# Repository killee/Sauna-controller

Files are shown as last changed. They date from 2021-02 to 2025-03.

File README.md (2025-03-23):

# Sauna-controller

<!-- Kurzbeschreibung -->
A fascinating and innovative project that implements a powerful sauna controller using ESPHome – smart, reliable, and highly impressive.

<!-- Inhaltsverzeichnis -->
- [Attention](#attention-working-with-line-voltage-is-very-dangerous-ensure-you-know-what-you-are-doing)
- [Sauna-controller](#sauna-controller)
- [Features](#features)
- [Components](#components)
- [System](#system)
- [Sauna lamp](#sauna-lamp)
- [Software](#software)
- [Circuit diagram](#circuit-diagram)
- [Things to do](#Things-to-do)
- [Installation](#installation)
- [Usage](#usage)
- [Repository Structure](#repository-structure)
- [Contributing](#contributing)
- [Inspiration](#inspiration)

# Attention: Working with line voltage is very dangerous! Ensure you know what you are doing!

# Sauna-controller
Sauna Controller with ESP8266/ESP32 and [ESPHome](https://esphome.io/) for integration with [Home Assistant](https://www.home-assistant.io/).

For about 60€, you get an awesome sauna controller!

The sauna controller is built from scratch with no additional components needed. Integration is done with Home Assistant, and the controller itself is built around the excellent [ESPHome](https://esphome.io/).

# Features
- Real PID controller
- Power and energy calculation
- Customizable
- No cloud dependency
- Remote access
- Expandable
- Affordable
- Reliable
- Easy to build
- Easy to use
- Open source

If you find a sauna controller with more features, let me know ;-)!

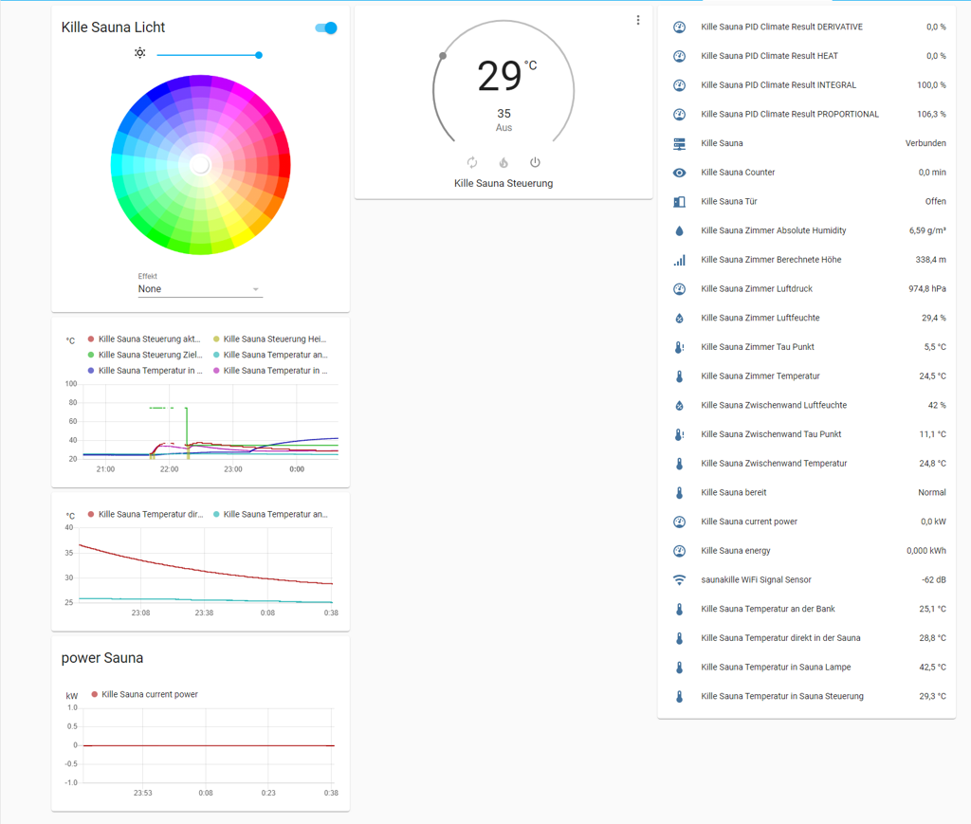
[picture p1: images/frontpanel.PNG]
Home Assistant

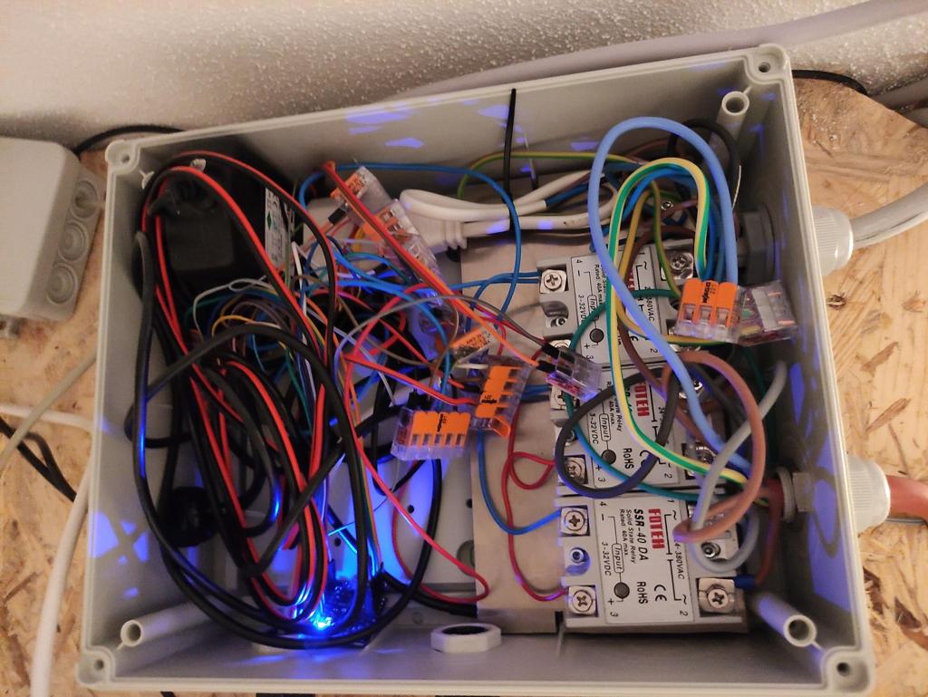
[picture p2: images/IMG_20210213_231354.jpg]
Sauna Controller

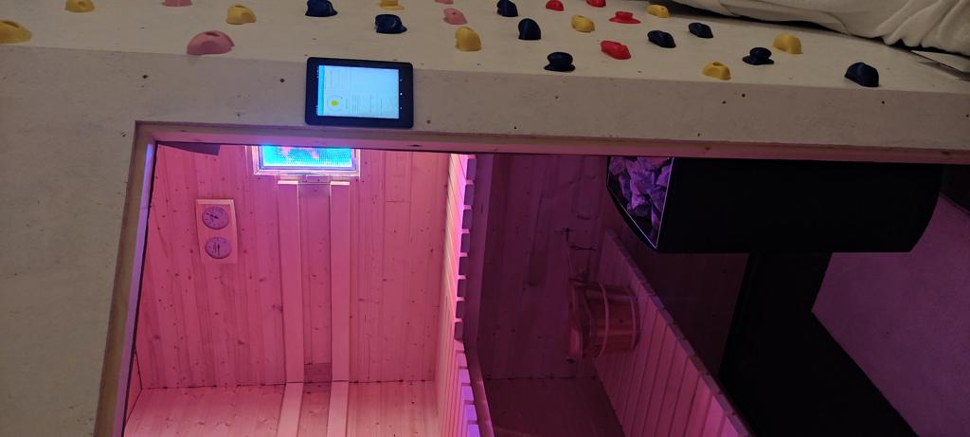
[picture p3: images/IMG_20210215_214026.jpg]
Sauna


# Components
Only a few components are needed:

1. **The brain of the Sauna Controller**: A Wemos D1 ESP8266 or any other device running ESPHome.

2. **Temperature sensors**: At least one DS18B20 to measure the temperature in the sauna. My setup includes 4 DS18B20 sensors to measure temperature at different locations (top of the sauna, lower bench, sauna controller, and sauna lamp).

3. **Thermal fuse**: A crucial component. If something goes wrong and the heater overheats, the thermal fuse burns out and switches off the heater, cutting the voltage for the high current switches.

4. **High current/voltage switch to heat the sauna**: I chose SSR relays like 3 SSR-40DA. SSR relays are wear-free and allow for easy PID controller implementation without noise.

5. **Optional door sensor**: I have a reed contact in the sauna door. If the door is open, the controller can switch off the sauna. The controller resets a timer when the door is opened, which is useful for extended sauna sessions.

6. **Optional additional sensors**: I use various other sensors to measure temperature in the room, between the sauna wall and the room wall, and humidity.

7. **Sauna lamp**: The controller also drives WS2812b LEDs for the sauna lamp, allowing for fun lighting effects.

8. **Junction box, cables, and other small components**.

# System
!Attention! Working with line voltage is very dangerous! Ensure you know what you are doing!

The heart of a sauna is, of course, the heater. Most commonly used heaters in Europe use 3-phase power and have a power rating of over 3kW, with a current of less than 16A. A normal switch for 3 phases is sufficient. The SSR-40DA, even the cheap copies, work well. Most SSR-40DA relays do not switch at 3.3V, even if the control LEDs turn on. With a simple NPN transistor, the three SSR-40DA relays get 5V control voltage and switch correctly. I mounted the SSR-40DA on an aluminum plate and tested the temperature of the plate. In the junction box, the temperature is about 50°C with my 7.5kW heater during the heating phase, which is acceptable.

I decided to switch the heater's 3 phases together for the lowest cable dissipation. The "PWM" has a long period of about 60 seconds, and the SSR-40DA relays have no switching wear. For safety, it is crucial to have a thermal fuse in the sauna. If the controller hangs or another bug occurs, the sauna can overheat, potentially leading to a fire. I use a thermal fuse with a 120°C rating in the control voltage for the SSR-40DA.

The rest of the controller is very simple. One DS18B20 measures the temperature, and that's it. The rest is handled by the ESP8266 (an ESP32 is also possible). See the Software section for more details. This setup provides a sauna controller that is more flexible than most commercial controllers, but for less money!

With the door sensor, you get additional features. A reed contact and magnet make it simple to wire like a normal switch with an internal pull-up. For about 1€, you can measure different temperatures in the sauna or the room.

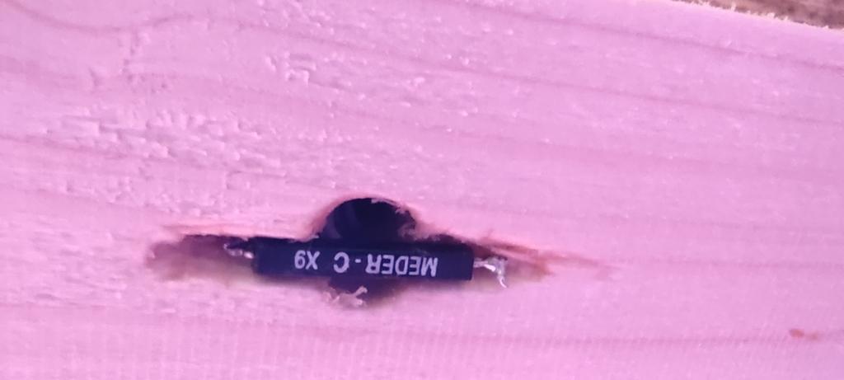
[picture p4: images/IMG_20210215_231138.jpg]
door sensor


I measure the temperature and humidity between the sauna wall and the room wall. The software calculates the dew point. If the dew point falls below the temperature, it can result in mildew. This allows me to react before mildew forms.

# Sauna lamp
A normal sauna lamp with a light bulb is not suitable for me. The biggest problem is the heat. Saunas with 100°C and LEDs don't work well together. I built a lamp with WS2812 LEDs, designed like an infinity lamp. The lamp dissipates heat with a large aluminum plate mounted on the outside wood. An acrylic "window" faces the sauna. With a temperature sensor in the lamp, it is possible to switch off the lamp before the LEDs overheat.

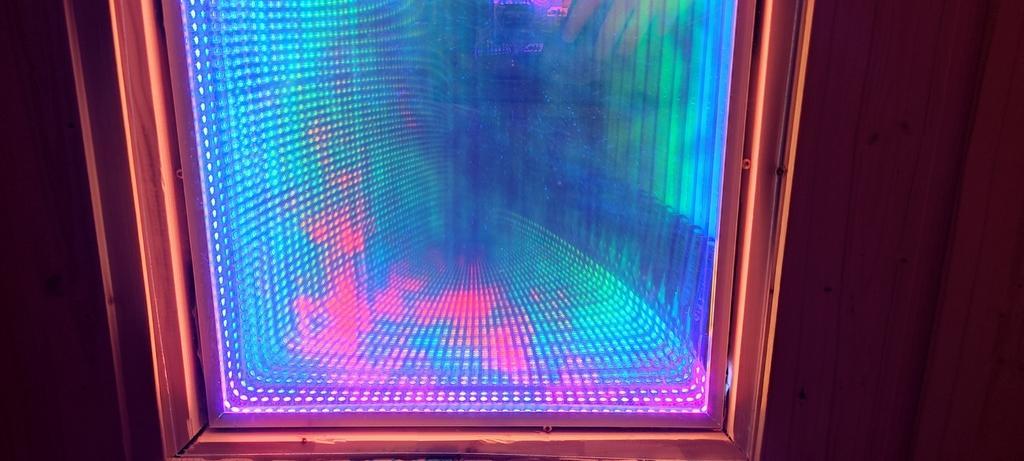
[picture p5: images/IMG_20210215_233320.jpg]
Sauna lamp


# Software
The sauna controller's entire UI is in [Home Assistant](https://www.home-assistant.io/). This is very convenient, as it prevents kids from accidentally turning on the sauna while playing in the sauna room. The software running on the controller is built with the excellent [ESPHome](https://esphome.io/). The configuration is in the sauna_controller.yaml file and is easily customizable for different setups.

In the Home Assistant frontend, you can set the temperature, switch the sauna on, and receive notifications when the sauna is ready. The controller itself manages the temperature without Home Assistant. If Home Assistant crashes, the sauna will not overheat. The controller regulates the heater with a PID controller, which works great. Compared to a simple two-point controller, the temperature is very stable. With a two-point controller, the temperature variation in the sauna is about 8°C. My heater makes noise when it switches off and on with a two-point controller, but with the PID controller, it is practically noiseless.

The PID constants are calculated with autotune. The constants are suitable for my sauna but can be optimized for different setups.

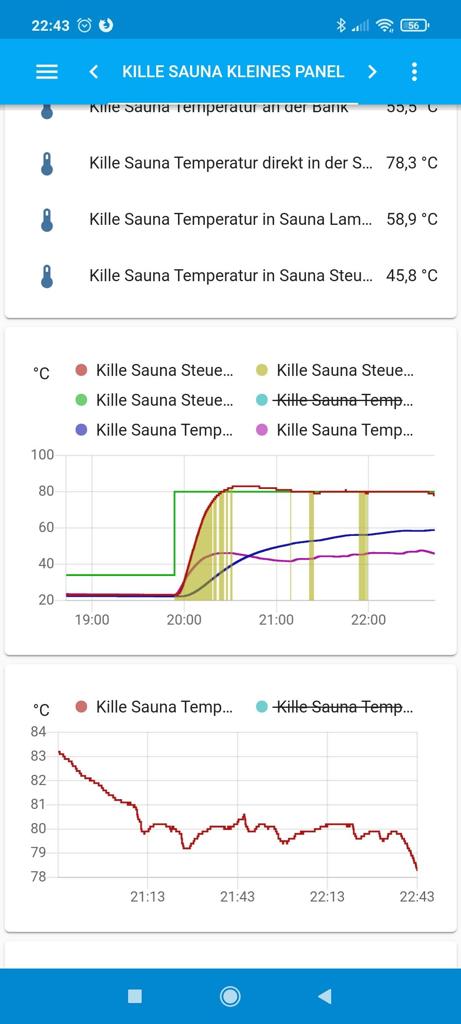
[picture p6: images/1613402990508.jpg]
temperature regulation


The controller also calculates the actual power needed for the sauna and integrates the power for the total energy consumption. This allows you to calculate the costs for your sauna sessions ;-).

With the door sensor, the timer resets if the door is opened. This is very convenient, as you don't need to remember to reset the timer. If you forget to close the door, the sauna will switch off.

I can measure different temperatures. Building a LED lamp for the sauna without overheating the LEDs was challenging. With a temperature sensor in the lamp, I was able to test if the heat dissipation was sufficient. The second attempt was successful ;-).

I've tried my best to comment the easy YAML config file, so it's easy to understand. It can be a good starting point for your own implementation.

# Circuit diagram
This is very simple. Normally, it is not needed, and the ESPHome YAML file is sufficient. But for reference, here is the circuit diagram:

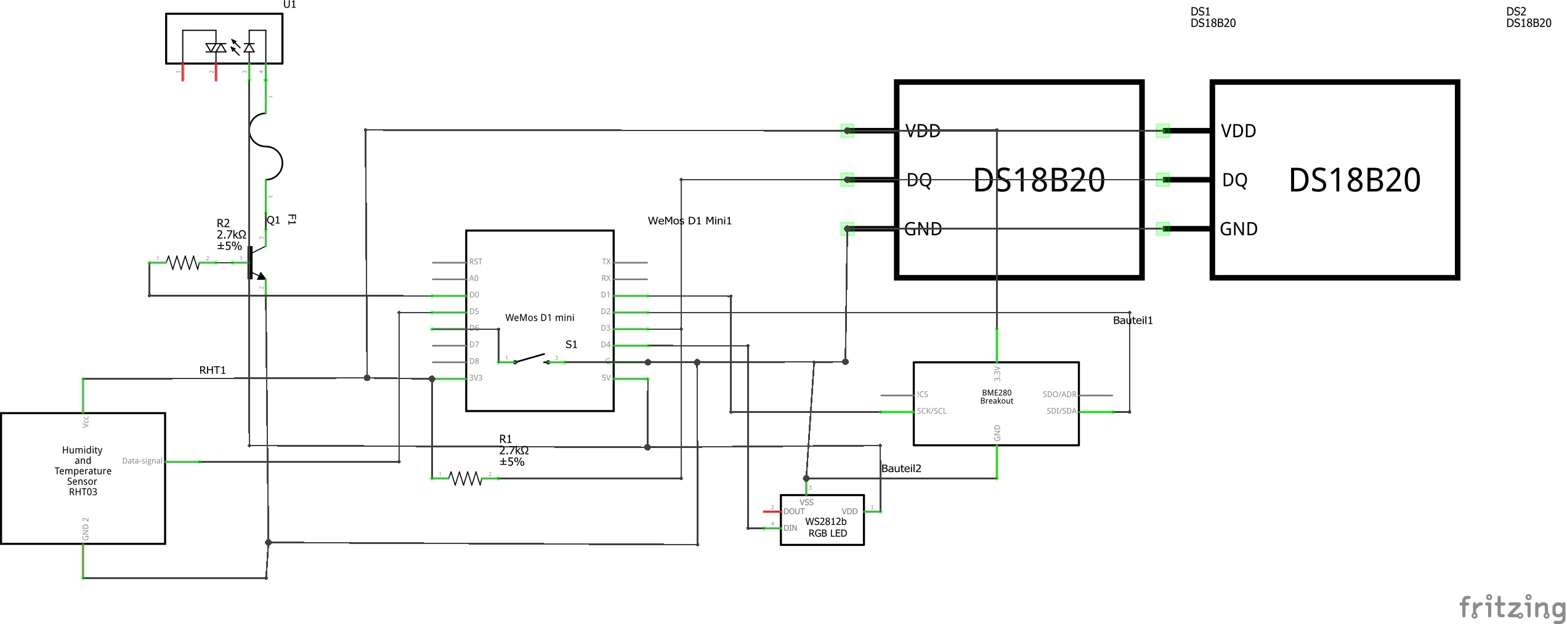
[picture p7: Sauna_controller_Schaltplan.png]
circuit diagram


## Circuit Diagram Explanation
1. **ESP8266/ESP32**: The brain of the controller, running ESPHome.
2. **SSR Relays (SSR-40DA)**: Used to switch the high current needed for the sauna heater. Controlled by the ESP8266/ESP32 through a transistor to provide the necessary control voltage.
3. **Temperature Sensors (DS18B20)**: Placed at various points to monitor the temperature inside the sauna (one for the pid at the seeling), optinal on the heatsink, and optinal in the room.
4. **Thermal Fuse**: !IMPORTANT! Provides a safety mechanism to cut off power if the temperature exceeds a safe limit.
5. **Door Sensor**: Optinal a reed switch that detects if the sauna door is open or closed.
6. **Sauna Lamp (WS2812 LEDs)**: Provides lighting inside the sauna with fun effects, controlled by the ESP8266/ESP32.
7. **Power Supply**: Provides the necessary power to the ESP8266/ESP32 and other components.

# Things to do
With the door contact, it would be possible to measure the time for a sauna session. A simulated sand clock with LEDs like WS2812 would be nice. Find more things to automate, such as switching off the room climate if the sauna is running, etc.

Very nice projects!

## Installation
- Flash the firmware with [ESPHome](https://esphome.io/).
- Connect your ESP8266/ESP32 device according to the pin mapping.
- Follow the on-screen instructions from Home Assistant and adjust settings in the YAML files as needed.

## Usage
- Integrate the controller with Home Assistant for easy control.
- Use the web interface to set target temperatures, view sensor status, and monitor energy consumption.
- The minimal version (sauna_simpler.yaml) is great for a lean setup, while sauna_controller.yaml offers extra features if you want advanced functionality.

## Repository Structure
- README.md – Project overview and documentation.
- sauna_simpler.yaml – Minimal configuration for essential operation.
- sauna_controller.yaml – A more feature-rich configuration with extra sensors and extras.
- images/ – Contains photos and the circuit diagram.

## Contributing
We welcome improvements!  
If you have suggestions or bug fixes, please open an issue or a pull request.

# Inspiration
This project was heavily inspired by:

https://github.com/bastiaanterhorst/sauna-automation  
https://github.com/quicklywilliam/saunakit

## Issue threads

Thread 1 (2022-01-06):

Fine regulation with ac_dimmer

eldarmusin, 2022-01-06:
I would like to contribute for those who cares in 4 steps.

**T Sensor**
For an experimental purpose, a used a DHT22 than switched for a 18ds20. Kept in code for the better comprehension.

**T Regulator**
I have used the same [pid ](https://esphome.io/components/climate/pid.html) component for the regulation, but as output used the [ac_dimmer](https://esphome.io/components/output/ac_dimmer.html) component. To set up the PID values Kp, Kd, Ki please see below.

**Dimmable Output**
I used the ac_dimmer component because of the [triac hardware](https://robotdyn.com/ac-light-dimmer-module-1-channel-3-3v-5v-logic-ac-50-60hz-220v-110v-1.html). The main advantages are:
- Price 2.5 € vs 10 € for an SSR
- The on state voltage is about 0.85V versus 1.6V of an SSR. And the power dissipation is than twice lower, as well as the dissipator for it
- You manage the max voltage on it. So you can reduce the wear of the oven (see max_power parameter)
- You manage the min voltage on it. So you can avoid the high frequency oscillations due to approaching the set point

**Set up PID**
I referred to the file [[Russian](http://www.termodat.ru/pdf/pid.pdf)] .

1. Set Kp = 100, Kd = Ki = 0 and let the system heat
2. You will see a Temperature curve of your sensor like this
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
3. After 4-5 oscillations, calculate the values as follows and report them to the code:
- Kp = 1.2 * DeltaT
- Ki = 1.5 * Tau
- Kd = 0.2 * Tau

Here is my code
sensor:
  - platform: dht
    pin: GPIO14
    temperature:
      id: sauna_temperature_sensor
      name: "Sauna temperature"
    humidity:
      name: "Sauna humidity"
    update_interval: 1s
    model: DHT22

output:
  - platform: ac_dimmer
    id: dimmer1
    max_power: 0.8
    min_power: 0.2
    gate_pin: GPIO32
    zero_cross_pin:
      number: GPIO33
      mode:
        input: true
      inverted: yes

climate:
  - platform: pid
    id: pid_climate
    name: "PID Sauna Controller"
    visual:
      min_temperature: 40 °C
      max_temperature: 90 °C
      temperature_step: 1 °C
    sensor: sauna_temperature_sensor
    default_target_temperature: 70°C
    heat_output: dimmer1
    control_parameters:
      kp: 1.44
      ki: 13.5
      kd: 1.8

killee, 2022-01-23:
Hi @eldarmusin

Thanks for your suggestions!

I didn't think about a triac control.
The power losses will be better and the power control is better.

Private people has also no responsibility about a not in Phase current.

I don't like this kind of triac power control, but that's my issue 😉.
Can you hear some line noise?

Why didn't you use the auto PID tune from esphome?

Regards

eldarmusin, 2022-02-23:
Yes I'm hearing a regulation noise. But after some time, just ignoring it.

The Auto PID hasn't worked for me for some reason. Had to find another solution.

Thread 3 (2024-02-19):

Which NPN Transistor?

janCGN, 2024-02-19:
Hey @killee ,
I have rebuilt the setup so far. Many thanks for the great description.
However, I am currently facing the problem that when "heating=off" the voltage at the SSR is 5V and when I switch it on it drops to 1.9V - so the 5V is only present in the "off" state. Is that normal?
You wrote something about the NPN transistor, can you tell me which one you used?

Thanks in advance

killee, 2024-03-15:
I'm so sorry for the late response.

I've used a bc547 with a 1kOhm resistor for the base.

I don't understand exactly where you measure the voltage. Can you describe it a bit?

Regards

Closed 2025-03-21.

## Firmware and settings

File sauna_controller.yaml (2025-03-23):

# Explanation:
# This YAML file is the minimalist approach - just the essentials to keep your sauna controller running.
# No unnecessary extras, simple and uncomplicated. Just the way you need it sometimes.

substitutions:
  devicename: saunakille
  user: Kille
  fullname: Killes Sauna
  max_power_generic: "1.0"
  #power of the sauna oven (kw dividet 100)
  power_of_sauna_oven: "0.075"

esphome:
    name: $devicename
    on_boot:
      priority: 200
      then:
        - climate.control:
            id: sauna_climate
            mode: 'OFF'

esp8266:  
  #platform: ESP8266
  board: d1_mini

wifi:
  ssid: !secret wifi_ssid
  password: !secret wifi_password

  # Enable fallback hotspot (captive portal) in case wifi connection fails
  ap:
    ssid: ${devicename} Fallback Hotspot"
    password: !secret wifi_password

#captive_portal:

# Enable logging
logger:

# Enable Home Assistant API
api:
  encryption:
    key: change_me

ota:
  platform: esphome
  password: !secret esp_password
  
#web_server:
#  port: 80

#Pinmapping
#D0 Sauna oven -> move to D7!
#D1 SCL
#D2 SDA
#D3 dallas
#D4 WS2812
#D5 DHT22
#D6 door reed contact

globals:
  - id: count_global_int
    type: int
    restore_value: no
    initial_value: '0'
  - id: count_global_door_int
    type: int
    restore_value: no
    initial_value: '0'

#the SSR relays for the sauna oven. They are switchted with a BC847 
output:
  - platform: slow_pwm
    pin: D0
    id: sauna_ofen_pwm
    period: 60s    

switch:
  - platform: template
    name:  ${user} Sauna PID Climate Autotune
    turn_on_action:
      - climate.pid.autotune: sauna_climate    


one_wire:
  - platform: gpio
    pin: D3
    #update_interval: 10s

i2c:
  sda: D2
  scl: D1
  scan: True
  id: bus_a


# Individual sensors
sensor:
  - platform: dallas_temp
    address: 0xD60516A1D5F6FF28 #Sensor on the seeling near by oven
    name: ${user} Sauna Temperatur direkt in der Sauna
    id: sauna_temp
    update_interval: 10s
  - platform: dallas_temp
    address: 0x11012042F8B5E128 #Sensor in the Sauna lamp 
    name: ${user} Sauna Temperatur in Sauna Lampe
  - platform: dallas_temp
    address: 0x8D0316A1D0C4FF28 #in the electronic at the SSR Relais
    name: ${user} Sauna Temperatur in Sauna Steuerung
  - platform: dallas_temp
    address: 0x07012042F262F228 #at a bench
    name: ${user} Sauna Temperatur an der Bank

  - platform: bme280_i2c #a sensor in the room of the Sauna
    temperature:
      name: ${user} Sauna Zimmer Temperatur
      oversampling: 16x
      id: bme280_temperature
    pressure:
      name: ${user} Sauna Zimmer Luftdruck
      id: bme280_pressure
    humidity:
      name: ${user} Sauna Zimmer Luftfeuchte
      id: bme280_humidity
    address: 0x76
    update_interval: 60s
  - platform: template
    name: ${user} Sauna Zimmer Berechnete Höhe
    lambda: |-
      const float STANDARD_SEA_LEVEL_PRESSURE = 1013.25; //in hPa, see note
      return ((id(bme280_temperature).state + 273.15) / 0.0065) *
        (powf((STANDARD_SEA_LEVEL_PRESSURE / id(bme280_pressure).state), 0.190234) - 1); // in meter
    update_interval: 60s
    icon: 'mdi:signal'
    unit_of_measurement: 'm'
  - platform: template
    name: ${user} Sauna Zimmer Absolute Humidity
    lambda: |-
      const float mw = 18.01534;    // molar mass of water g/mol
      const float r = 8.31447215;   // Universal gas constant J/mol/K
      return (6.112 * powf(2.718281828, (17.67 * id(bme280_temperature).state) /
        (id(bme280_temperature).state + 243.5)) * id(bme280_humidity).state * mw) /
        ((273.15 + id(bme280_temperature).state) * r); // in grams/m^3
    accuracy_decimals: 2
    update_interval: 60s
    icon: 'mdi:water'
    unit_of_measurement: 'g/m³'
  - platform: template
    name: ${user} Sauna Zimmer Tau Punkt
    lambda: return (243.5*(log(id(bme280_humidity).state/100)+((17.67*id(bme280_temperature).state)/(243.5+id(bme280_temperature).state)))/(17.67-log(id(bme280_humidity).state/100)-((17.67*id(bme280_temperature).state)/(243.5+id(bme280_temperature).state))));
    unit_of_measurement: °C
    icon: 'mdi:thermometer-alert'
  - platform: dht #a sensor in the gap beetween the sauna wall and the wall of the room
    model: dht22    
    pin: D5
    temperature:
      name: ${user} Sauna Zwischenwand Temperatur
      id: dht22_temperature
    humidity:
      name: ${user} Sauna Zwischenwand Luftfeuchte
      id: dht22_humidity
  - platform: template
    name: ${user} Sauna Zwischenwand Tau Punkt
    lambda: return (243.5*(log(id(dht22_humidity).state/100)+((17.67*id(dht22_temperature).state)/(243.5+id(dht22_temperature).state)))/(17.67-log(id(dht22_humidity).state/100)-((17.67*id(dht22_temperature).state)/(243.5+id(dht22_temperature).state))));
    unit_of_measurement: °C
    icon: 'mdi:thermometer-alert'
    update_interval: 60s
  - platform: template #gives the counter without a change back to HA (for debugging or so)
    name: ${user} Sauna Counter
    unit_of_measurement: 'min'
    lambda: |-
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

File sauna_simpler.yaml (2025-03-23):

# Explanation:
# This YAML file is the minimalist approach - just the essentials to keep your sauna controller running.

substitutions:
  devicename: "Sauna Controller"
  internalname: "sauna-controller"
  #power of the sauna oven kw
  power_of_sauna_oven: "6.50"

esphome:
  name: "${internalname}"
  on_boot:
    priority: 200
    then:
      - climate.control:
          id: sauna_climate
          mode: 'OFF'

esp32:
  board: esp32dev
  framework:
    type: arduino

wifi:
  ssid: !secret wifi_ssid
  password: !secret wifi_password

  # Enable fallback hotspot (captive portal) in case wifi connection fails
  ap:
    ssid: ${devicename}
    password: !secret wifi_password


# Enable logging
logger:

# Enable Home Assistant API
api:
  #password: !secret esp_password

ota:
  platform: esphome
  password: !secret esp_password


one_wire:
  - platform: gpio
    pin: 23

globals:
  - id: sauna_runtime
    type: int
    restore_value: no
    initial_value: '0'  # In seconds

sensor:
  # Change the addresses below according to the addresses present in your controller
  - platform: dallas
    address: 0x523c01d607567d28
    name: "${devicename} Heatsink"
    id: heatsink_temp
    entity_category: diagnostic

  - platform: dallas
    address: 0x4d0120633b2fc328
    name: "${devicename} Above Oven"
    id: sauna_temp

  - platform: dallas
    address: 0x623c01d607fa4728
    name: "${devicename} Room"

  - platform: template
    name: "Timer ${devicename}"
    id: sauna_timer
    unit_of_measurement: s
    accuracy_decimals: 0
    lambda: |-
      return id(sauna_runtime);

  - platform: pid
    climate_id: sauna_climate
    name: "Sauna Current Power ${devicename}"
    type: HEAT
    filters:
      - multiply: ${power_of_sauna_oven}
      - multiply: 0.01
    unit_of_measurement: 'kW'
    id: power_of_sauna
    force_update: true

  - platform: integration
    name: "Sauna Energy ${devicename}"
    sensor: power_of_sauna
    time_unit: h
    restore: true
    state_class: total_increasing
    device_class: energy

binary_sensor:
  - platform: template
    name: "${devicename} Sensor Error"
    id: sauna_sensor_failure
    lambda: |-
      if (isnan(id(sauna_temp).state) || !id(sauna_temp).has_state()) {
        return true;
      } else {
        return false;
      }

climate:
  - platform: pid 
    id: sauna_climate
    name: "Sauna Control ${devicename}"
    sensor: sauna_temp
    default_target_temperature: 5°C
    heat_output: sauna_ofen_pwm
    # Set the PID parameters for your sauna these are just examples suitable for my sauna with 6.5kW and 5.8m³
    # You can use the PID Tuner in the ESPHome to find the best values for your sauna
    # the results are amazing! Try it out!
    control_parameters:
      kp: 0.19181
      ki: 0.00015
      kd: 75.09859

    visual:
      min_temperature: 10 °C
      max_temperature: 100 °C
      temperature_step: 1 °C

light:
  - platform: binary
    name: "Light in ${devicename}"
    output: sauna_light

switch:
  - platform: gpio
    pin: 27
    name: "${devicename} Phase 1"
    id: phase1
    restore_mode: ALWAYS_OFF
    entity_category: diagnostic
    inverted: true
  - platform: gpio
    pin: 26
    name: "${devicename} Phase 2"
    id: phase2
    restore_mode: ALWAYS_OFF
    entity_category: diagnostic
    inverted: true
  - platform: gpio
    pin: 25
    name: "${devicename} Phase 3"
    id: phase3
    restore_mode: ALWAYS_OFF
    entity_category: diagnostic
    inverted: true

output:
  - platform: slow_pwm
    id: sauna_ofen_pwm
    period: 60s
    turn_off_action:
      - switch.turn_off: phase1
      - switch.turn_off: phase2
      - switch.turn_off: phase3
    turn_on_action:
      - switch.turn_on: phase1
      - switch.turn_on: phase2
      - switch.turn_on: phase3

  - platform: gpio
    pin: GPIO16
    id: sauna_light
    inverted: true

interval:
  - interval: 30s
    then:
      - if:
          condition:
            or:
              - lambda: "return isnan(id(sauna_temp).state);"
              - lambda: "return !id(sauna_temp).has_state();"
          then:
            - climate.control:
                id: sauna_climate
                mode: 'OFF'
            - lambda: |-
                id(sauna_runtime) = 0;
          else:
            - if:
                condition:
                    lambda: "return id(sauna_climate).mode == climate::CLIMATE_MODE_HEAT;"                
                then:
                  - lambda: |-
                      id(sauna_runtime) += 30;
                else:
                  - lambda: |-
                      id(sauna_runtime) = 0;

      - if:
          condition:
            lambda: "return id(sauna_runtime) >= (6*60*60);"
          then:
            - climate.control:
                id: sauna_climate
                mode: 'OFF'
            - lambda: |-
                id(sauna_runtime) = 0;

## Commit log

2021-02-13 Changes to be committed: new file: Sauna_Steuerung.fzz new file: Sauna_controller_Schaltplan.png new file: images/IMG_20210213_231354.jpg new file: images/IMG_20210213_231534.jpg new file: images/IMG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
    [Sauna_Steuerung.fzz, sauna_controller.yaml]
2021-04-13 modified: sauna_controller.yaml fixed issus after power resets
    [sauna_controller.yaml]
2025-03-21 Refactor sauna_controller.yaml and add sauna_simpler.yaml for improved configuration and functionality
    [sauna_controller.yaml]
2025-03-23 Update README.md and YAML files to enhance documentation and provide minimalist configuration explanations
    [sauna_controller.yaml]
